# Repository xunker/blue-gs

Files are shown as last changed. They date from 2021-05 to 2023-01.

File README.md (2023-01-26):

# BlueGS: Internal BlueSCSI for Apple IIgs and //e

*BlueGS* is the internal hard drive your Apple IIgs and //e always *craved*.

Using the [BlueSCSI](https://github.com/erichelgeson/BlueSCSI) SCSI drive emulator and your compatible SCSI card, you have a fully internal hard drive with accessible microSD slot while still keeping your DB-25 connector free for other peripherals.

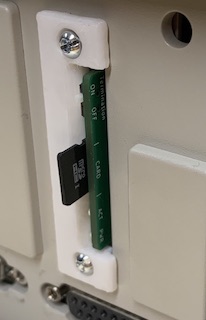
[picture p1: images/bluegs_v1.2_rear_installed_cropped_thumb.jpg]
Close-up of BlueGS installed in IIgs slot

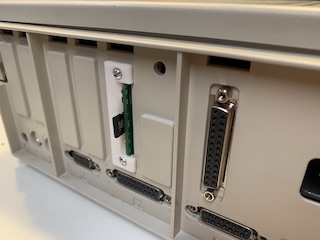
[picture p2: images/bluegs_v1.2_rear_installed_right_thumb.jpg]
BlueGS installed in IIgs slot, right side

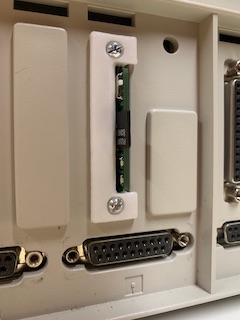
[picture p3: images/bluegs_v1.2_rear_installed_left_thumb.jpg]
BlueGS installed in IIgs slot, left side


# How it works

BlueGS connects between your SCSI card and its external DB-25 connector to give you a seamless installation. The BlueGS module itself mounts in a free DB-25 connector cutout in the rear of your IIgs or //e.

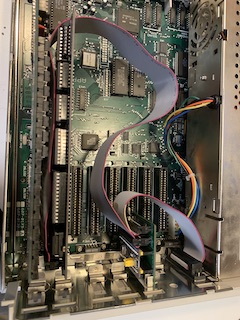
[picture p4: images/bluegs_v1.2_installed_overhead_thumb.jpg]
Overhead view of BlueGS in IIgs slot

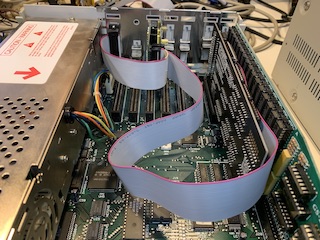
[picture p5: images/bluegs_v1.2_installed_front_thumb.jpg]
Frontal view of BlueGS in IIgs slot


# Features

* Gives your Apple IIgs or //e an internal, cable-free hard drive
* Can be powered from SCSI termination power only (if present)
* "Termination Power" mod is not required (when powered from auxiliary 5V source)
* Can *provide* termination power to the SCSI bus (when powered from a 5V source such as the Game IO connector or card slot)
* Built-in termination that is controlled with a single switch
* Active termination ICs instead of passive termination resistors, reduces power consumption by over 2/3rds
* Reverse current and voltage protection with overcurrent prevention for auxiliary 5V input
* Connection for external drive activity LED

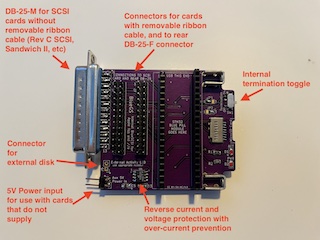
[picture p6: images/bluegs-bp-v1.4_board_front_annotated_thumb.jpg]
Annotated picture of front of BlueGS v1.2

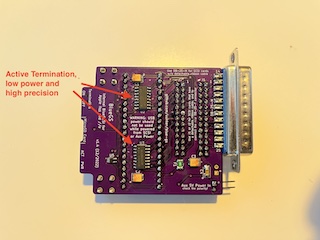
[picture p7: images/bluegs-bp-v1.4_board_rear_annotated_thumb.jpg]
Annotated picture of rear of BlueGS v1.2


# Compatible SCSI cards

Tested:
* [GGLabs A2SCSI](https://gglabs.us/node/2071) - a clone of the Apple Rev C SCSI card
* Apple Rev C SCSI and clones
* Apple High-Speed SCSI ("Sandwich II")
* Ramfast SCSI

Assumed to work:
* GSE-Reactive SCSI Card

Untested:
* AMR SCSI
* Cirtech SCSI/Insyder
* SVA Hard Disk Adapter

The CMS SCSI II is currently confirmed **NOT** to work, though it appears to be a (card) firmware issue and not a "bug" with BlueSCSI.

## What if my SCSI card doesn't provide termination power?

Running BlueGS from "termination power" makes installation much easier, but not all SCSI cards have it. For more details, please check out the notes on [Powering BlueGS](POWERING_BLUE-GS.md).

# Performance

Using [BenchmarkD](https://www.brutaldeluxe.fr/products/apple2gs/benchmarked.html) with Apple IIgs (ROM 1, "Fast" speed), GS-RAM Plus w/ 2MB, GGLabs A2SCSI card. Using Blue-Pill-based BlueGS board.

* Read
  * File: 52 KB/s
  * Block-by-block: 36 KB/s
  * With 64K buffer: 79 KB/s
* Write (File): 37 KB/s

# Can I use it on things besides the IIgs and //e?

Yes! It's a standard BlueSCSI device and uses the standard BlueSCSI V1 firmware. In fact, the built-in DB-25 connector makes it the perfect external SCSI drive as well!

BlueGS can be mounted internally in any computer that has an open cutout for a DB-25 connector.

## ✅ Compatible Apple clones

These computers *do* have rear DB-25 cutouts and so BlueGS should be able to mount properly, but are untested.

* Franklin Ace 2000/2100/2200
* Basis 108

## 🚫 Apple II/II+ and similar clones

BlueGS will function in an Apple II or II+, but you will not be able to mount it because it uses "V" shaped cutouts instead of D-Subminiature connector cutouts like the //e and IIgs have.

Many Apple II clones use the same rear cutout design and have the same mounting limitation. **A mounting solution for these machine is planned**.

* Franklin Ace 100/1000/1200
* Pravetz-8
  - Includes the -8, -82, -8M, -8A, -8E, and -8C
* Unitron (Brazil)
* Ci Base-48 and Pineapple (Korea)

# Assembly

If you purchased BlueGS as a self-assemble kit or are using your own PCBs, please follow the instructions in the "[assembly](assembly/)" directory.

If your BlueGS was purchased fully-assembled, please move on to the "[Installation](installation/)" section.
# Installation

Installation guides can be found in the "[installation](installation/)" directory.
# Schematics

[V1.4 Schematic](schematics/schematic_v1.4.pdf) (**FINAL**, recommended design)

<details>
  <summary>Older Schematics</summary>

[V1.3 Schematic](schematics/schematic_v1.3.pdf)

[V1.2 Schematic](schematics/schematic_v1.2.pdf)

[V1.1 Schematic](schematics/schematic_v1.1.pdf)

</details>

# EDA/Kicad and Gerber Files

Kicad of current design can be found in [kicad](kicad/) directory.

# Credits

This project would not be possible without the work done by [ztto](https://github.com/ztto/ArdSCSino-stm32), [Tambo](https://twitter.com/h_koma2), [Eric Helgeson](https://github.com/erichelgeson/BlueSCSI), [Androda](https://androda.work/), and many others.

The "Blue Pill" footprint was originally created by [Yet-Another-Average-Joe](https://github.com/yet-another-average-joe/Kicad-STM32).

Symbol and footprint for Molex 105162-0001 MicroSD slot created by [SnapEDA user HMantz](https://www.snapeda.com/parts/105162-0001/Molex/view-part/).

# License

See [LICENSE.md](LICENSE.md).

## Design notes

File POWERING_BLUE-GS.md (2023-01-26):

# Powering BlueGS

There are 4 ways to power your BlueGS board, listed here from "most easy" to "least easy".

## Termination Power from SCSI card

If your SCSI card provides [Termination Power](#what-is-termination-power), then you only have to BlueGS to your SCSI card using the included flat 26-pin cable or DB-25-M connector. No additional steps are required, and BlueGS should turn on the moment that the computer is powered up.

## Termination Power from another SCSI device

If your SCSI card does not provide Termination Power, then you can provide the necessary power through another SCSI device connected to the DB-25 connector.

Most external SCSI devices will provide the necessary Termination Power. To power BlueGS this way:
* Connect the new SCSI device to the DB-25 connector
* On BlueGS, switch "Termination" to "off"
* Ensure that the new SCSI device is terminated, either via a switch (if it has one, such as on the IOmega Zip Drive) or an external terminator that connects to one of the SCSI ports of the device.

This external device must be powered-on *before* the IIgs turns on.

## +5V from inside the computer

You can power BlueGS via the "Aux 5V Power In" connector, using a 5V source in your computer. This can be from the Game IO port, a card slot, or a tap from the power supply rail.

If you power BlueGS using this connector, it will also send termination power to any other devices on the SCSI bus that may need it -- such as another BlueSCSI device!

Older versions of BlueGS could be powered by the 12V fan connector in the IIgs, but that has been removed in 1.4 and higher.

## USB port on Blue Pill board

You can power BlueGS using the USB connector on the Blue Pill module as long as you are not also using SCSI Termination Power or 5V aux power.

### Why can't I use USB while BlueGS is powered from SCSI or Aux?

There is a design flaw on the Blue Pill board where power sent to the +5V pin of the board can then be sent *back* through the USB connector. This "backflow" can potentially cause damage to whatever is providing USB power and so it strongly recommended that you do not use USB to power BlueGS while connected to SCSI Termination Power or aux power.

If there is no termination power on your bus and BlueGS is not using the aux power connector, then there is no danger of "backflow" and USB power can be used.

# What is Termination Power?

Very briefly, "Termination Power" is electrical current that is used to power devices called "Terminators". A "Terminator" is a device connected to the end of a "bus" (the cable/wire) to show where the end is.

If you think of the SCSI bus as a water pipe and each drive on the bus as a water tap connected to the pipe, then a Terminator is the cap at the end of the pipe.

# What SCSI cards do/don't provide Termination Power?

While many SCSI cards do not provide termination power, there are some that can be modified to that they will.

## Cards that DO provide Termination Power

* [GGLabs A2SCSI](https://gglabs.us/node/2071)
* RAMFast SCSI - controlled by JP1 or DIP #1, see manual for details

## Cards that DON'T provide Termination Power

* Apple Rev B SCSI
  - Can be modified to provide termination power
* Apple Rev C SCSI
  - Can be modified to provide termination power
* Apple High-Speed SCSI ("Sandwich II")
  - Can be modified to provide termination power

## Unknown cards

* AMR SCSI
* CMS SCSI II
* Cirtech SCSI/InSyder
* GSE-Reactive SCSI Card
* SVA Hard Disk Adapter

# How can I tell if my SCSI card is providing Termination Power?

If your card is not in one of the lists above, then the easiest way is to connect BlueGS and see if it turns on when the the computer is powered on.

If you have a multi-meter, you can check the voltage on pin 25 of the DB-25 connector. If termination power is provided, this pin should read between 4.5 and 5 volts.

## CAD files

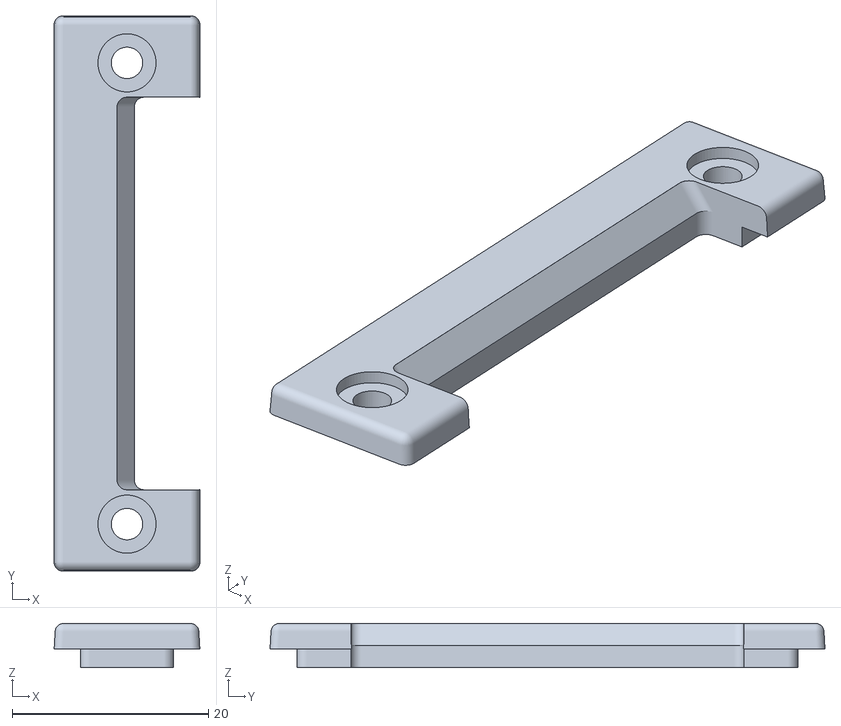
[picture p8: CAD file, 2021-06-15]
slot_cover/blue-gs-cover.stl
14.8 x 56.5 x 4.50

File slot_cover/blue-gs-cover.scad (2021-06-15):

face_length = 56.55;
face_width = 14.85;
face_thickness = 2.6;
face_inset = (face_width - 14.65)/2; // amount the sides will slope inward, per side

rear_length = 51.0;
rear_width = 9.5;
rear_thickness = 4.5 - face_thickness;

screw_spacing = 47;
screw_d = 3.1;
screw_head_d = screw_d * 1.85;
screw_head_t = face_thickness * 0.4;
slope_screw_heads = false;

notch_width = 7.5;
notch_length = 39;
notch_x_offset = 4.5; // from centreline

total_thickness = face_thickness + rear_thickness;

ff = 0.01;

$fn = 64;

// inset is how far in the sides will slop, per side
module rounded_top_rectangle(width, length, height, inset=0, rad=6) {
  hull() {
    // rounded sides
    // translate([rad,rad,0]) cylinder(r=rad, h=height-rad);
    // translate([width-rad,rad,0]) cylinder(r=rad, h=height-rad);
    // translate([width-rad,length-rad,0]) cylinder(r=rad, h=height-rad);
    // translate([rad,length-rad,0]) cylinder(r=rad, h=height-rad);
    translate([rad,rad,0]) cylinder(r=rad, h=ff);
    translate([width-rad,rad,0]) cylinder(r=rad, h=ff);
    translate([width-rad,length-rad,0]) cylinder(r=rad, h=ff);
    translate([rad,length-rad,0]) cylinder(r=rad, h=ff);

    // rounded top
    translate([rad+inset,rad+inset,height-rad]) sphere(r=rad);
    translate([width-(rad+inset),(rad+inset),height-rad]) sphere(r=rad);
    translate([width-(rad+inset),length-(rad+inset),height-rad]) sphere(r=rad);
    translate([(rad+inset),length-(rad+inset),height-rad]) sphere(r=rad);

  }
}

module rounded_rectangle(width, length, height, inset=0, rad=6, fn=32) {
  hull() {
    // rounded sides
    translate([rad,rad,0]) cylinder(r=rad, h=height);
    translate([width-rad,rad,0]) cylinder(r=rad, h=height);
    translate([width-rad,length-rad,0]) cylinder(r=rad, h=height);
    translate([rad,length-rad,0]) cylinder(r=rad, h=height);
  }
}

module face() {
  intersection() {
    cube([face_width, face_length, face_thickness]);

    rounded_top_rectangle(face_width, face_length, face_thickness, inset=face_inset, rad=face_thickness/3);

  }
}

module rear() {
  rounded_rectangle(rear_width, rear_length, rear_thickness, rad=1);
}

module blank_cover() {
  difference() {
    union() {
    translate([(face_width-rear_width)/2, (face_length-rear_length)/2, 0]) rear();
    translate([0, 0, rear_thickness]) face();
    }
    translate([face_width/2, face_length/2, -ff]) for (sign=[1,-1]) {
      translate([0, (screw_spacing/2)*sign, 0]) {
        cylinder(d=screw_d, h=total_thickness+(ff*2));
        translate([0, 0, total_thickness-screw_head_t]) {
          if (slope_screw_heads) {
            cylinder(d1=screw_d, d2=screw_head_d, h=screw_head_t+(ff*2));
          } else {
            cylinder(d=screw_head_d, h=screw_head_t+(ff*2));
          }
        }
      }
    }
  }
}

difference() {
  blank_cover();
  translate([((face_width-notch_width)/2) + notch_x_offset, (face_length-notch_length)/2, -ff]) {
    flared_width = (face_width-notch_width)*1.5;
    flared_length = notch_length * 1.0;

    rounded_rectangle(notch_width, notch_length, total_thickness/2, rad=1);
    translate([0, 0, (total_thickness/2)-ff]) hull() {
      rounded_rectangle(notch_width, notch_length, ff, rad=1);
      translate([(notch_width-flared_width)/2, (notch_length-flared_length)/2, (total_thickness/2)+ff])
        rounded_rectangle(flared_width, flared_length, ff, rad=1);
    }
  }
}

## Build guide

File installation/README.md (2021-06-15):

# BlueGS Installation Guide

<!-- TOC -->

- [BlueGS Installation Guide](#bluegs-installation-guide)
- [Introduction](#introduction)
- [Steps](#steps)
- [Open computer case](#open-computer-case)
- [Remove rear slot cover](#remove-rear-slot-cover)
- [Unscrew DB-25 Connector](#unscrew-db-25-connector)
- [Remove SCSI card](#remove-scsi-card)
- [Move DB-25 connector](#move-db-25-connector)
- [Attach ribbon cable](#attach-ribbon-cable)
- [Install BlueGS in rear slot](#install-bluegs-in-rear-slot)
- [Reinstall DB-25 connector in rear slot](#reinstall-db-25-connector-in-rear-slot)
- [Reinstall SCSI card and close computer case](#reinstall-scsi-card-and-close-computer-case)
- [Insert MicroSD card, check termination](#insert-microsd-card-check-termination)
- [Power on and enjoy!](#power-on-and-enjoy)

<!-- /TOC -->
# Introduction

Before continuing, please ensure you have all the required parts ready:

* Assembled BlueGS board, including "Blue Pill" module (See [assembly guide](../assembly/) for more info)
* Rear slot cover
* 2x screws for rear slot cover ("US Machine Screw" size: #4-40, length: > 0.75in/15mm)
* 26-pin ribbon cable

# Open computer case

Turn off the computer power switch and unplug the power connector.

Open the top cover of the computer case.

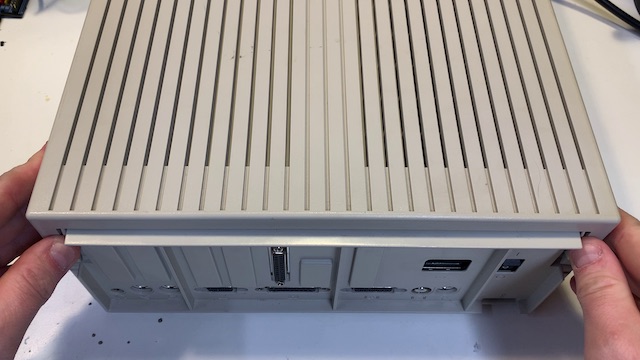
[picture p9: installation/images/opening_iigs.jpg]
Opening IIgs cover


Before continuing, it is recommended that your remove any static electricity from you body by "grounding" yourself. To do this, touch the metal part of any electrical appliance that uses a grounded/earthed electrical plug (the outside of a metal surge protector, for example).

# Remove rear slot cover

Find an unused DB-25 slot cover. The DB-25 slots are the longest, and a usable slot will be the same length as the slot already used for the external connector of your SCSI card.

To remove the cover, grasp the metal tab on the inside of the slot and turn counter-clockwise for 1/4 of a turn. Remove the metal tab, and the plastic slot cover should fall away.

Keep both the metal tab and the plastic cover for later re-use as these parts are very hard to replace.

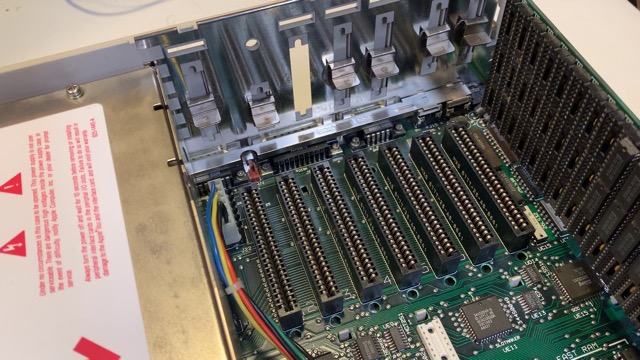
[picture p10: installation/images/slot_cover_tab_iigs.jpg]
IIgs slot cover tabs

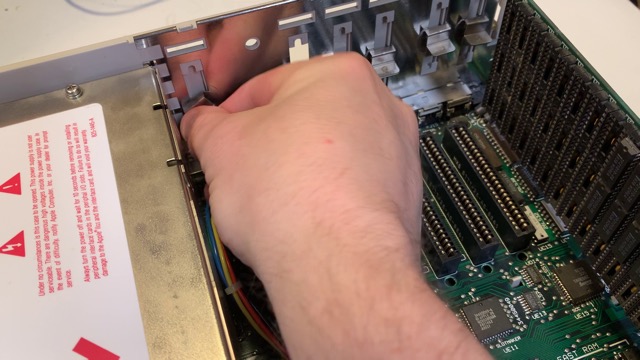
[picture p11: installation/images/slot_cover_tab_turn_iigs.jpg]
IIgs slot cover tab removal


# Unscrew DB-25 Connector

Find the existing connector for the SCSI card on the rear of the computer. It may look similar to connector for a serial card, so make sure you find the correct connector. Using a small socket or needle-nose pliers, loosen the two screw mounts on either end of the connector and remove them. The DB-25 connector should now be freed.

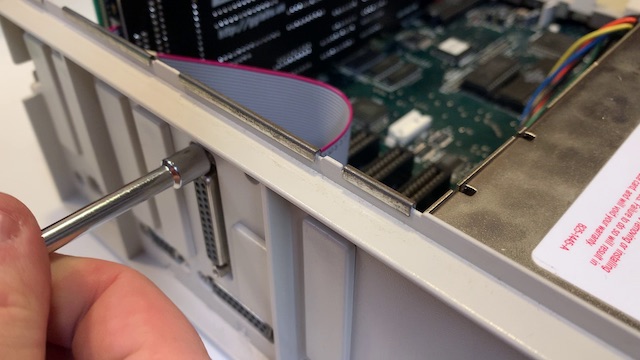
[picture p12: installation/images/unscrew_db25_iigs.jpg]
IIgs DB-25 Connector Removal


# Remove SCSI card

Find your SCSI card (typically in slot #7) and remove it by pulling it firmly upward.

IMPORTANT: While removing the card, ensure the cable for the DB-25 connector (see previous step) is kept away from the metal tabs on the rear of the computer case. These tabs can be **sharp** and can damage the cable.

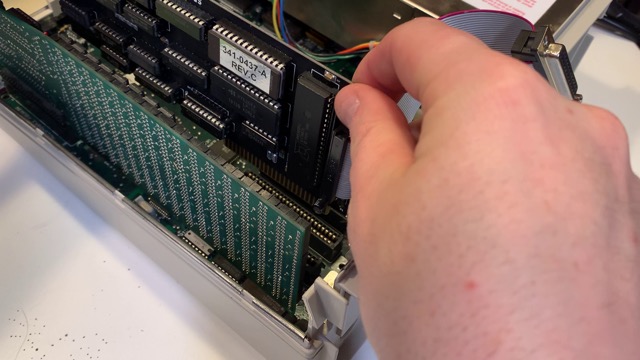
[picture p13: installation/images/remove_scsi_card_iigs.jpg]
IIgs SCSI Card Removal

# Move DB-25 connector

With the SCSI card out of the machine, look at the long rectangular connection where the DB-25 cable connects to the SCSI card (known as an "IDC connector"). Note where "Pin 1" is oriented. Pin 1 is usually marked by a red stripe.

Next, remove the DB-25 connector from the SCSI card. Do this by grasping the IDC connector on the SCSI card and gently pulling away from the board.

Next, take the IDC connector on the DB-25 cable and connect it the BlueGS board. It can connect to *either* connector J1 or J2.

When connecting the cable, make sure that **Pin 1** is correctly aligned. On the cable, Pin 1 is usually marked by a red stripe. On BlueGS, Pin 1 for connectors J1 and J2 are those closest to the top-left corner and the pins are marked with a "1" on the board next to them.

IMPORTANT: Again, *make sure* pin 1 is correctly aligned.

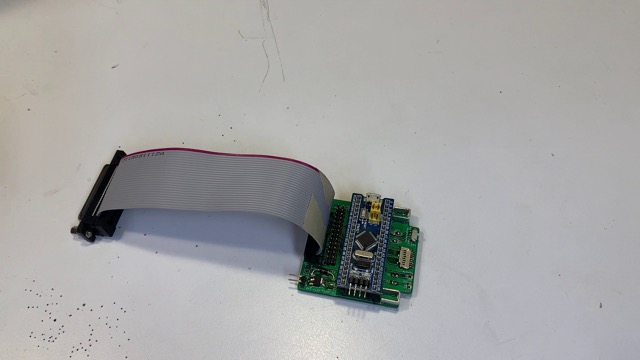
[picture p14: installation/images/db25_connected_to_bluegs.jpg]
DB-25 connected to BlueGS


# Attach ribbon cable

Take the included ribbon cable and attach one end to BlueGS. Use either J1 or J2, whichever connector is not used by the DB-25 connector in the previous step. As before, ensure that Pin 1 is correctly aligned.

Then, connect the other end of the ribbon cable to the SCSI card. Plug it in so that Pin 1 of the ribbon cable is in the same place where Pin 1 of the DB-25 cable was previously.

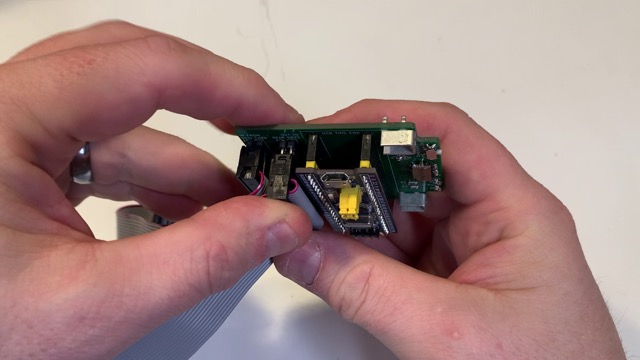
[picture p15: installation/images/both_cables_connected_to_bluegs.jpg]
DB-25 and ribbon cable connected to BlueGS


# Install BlueGS in rear slot

Place BlueGS so the edge with the MicroSD slot, LEDs, and switch is inside one of the open slots on the rear of the computer. It is recommended to orient BlueGS so that the USB port is pointed upwards.

Place the included slot cover on the *outside* of the case over the appropriate slot and thread the included screws through the two screw holes and in to the brackets on BlueGS.

Once the screws are correctly threaded, gently tighten them down with a screwdriver until BlueGS is firmly attached to the slot.

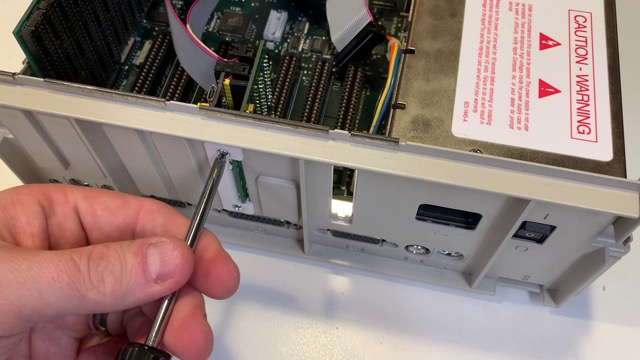
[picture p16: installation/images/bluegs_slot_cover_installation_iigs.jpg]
BlueGS in IIgs rear slot


# Reinstall DB-25 connector in rear slot

In the remaining open slot, reinstall the DB-25 connector.

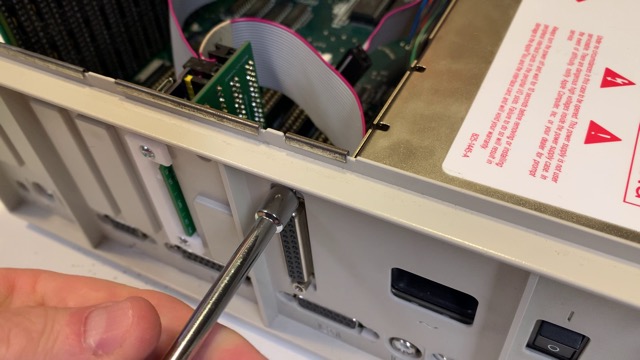
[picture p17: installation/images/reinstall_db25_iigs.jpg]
Reinstall DB-25 connector in IIgs rear slot


# Reinstall SCSI card and close computer case

Reinstall the SCSI card in the correct slot and replace the cover on the computer.

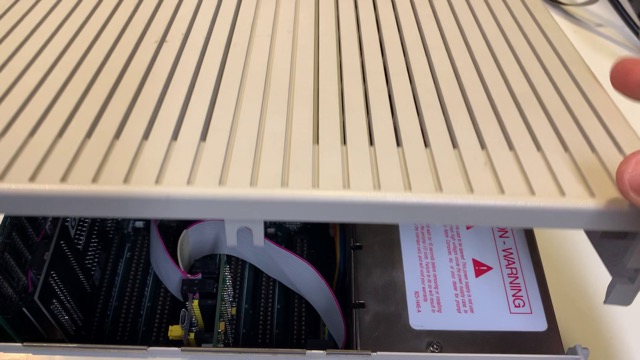
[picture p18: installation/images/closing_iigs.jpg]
Closing IIgs case


# Insert MicroSD card, check termination

Take a MicroSD card that has been previously prepared (instruction [here](https://github.com/erichelgeson/BlueSCSI/wiki/Usage)) and insert it in to the slot on the rear.

If you have no other SCSI devices connected to your computer, the "Termination" switch should be set to "On".

# Power on and enjoy!

Reconnect all necessary cables, turn on the power and enjoy.

The "Power" LED should light the moment the computer turns on, and the "ACT" LED should light whenever the emulated SCSI drive is being read or written.

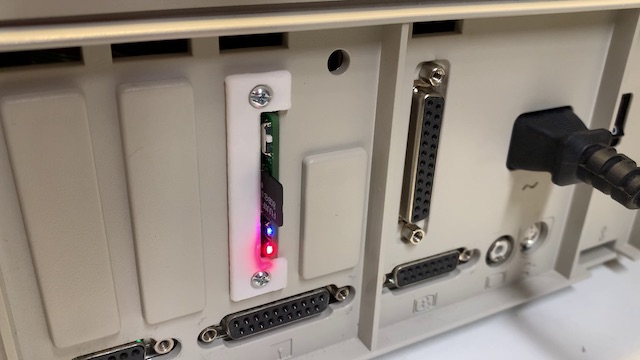
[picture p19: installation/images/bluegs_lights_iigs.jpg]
Show Power and Activity LEDs on BlueGS installed in IIgs


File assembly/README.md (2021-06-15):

# BlueGS Assembly Guide

<!-- TOC -->

- [BlueGS Assembly Guide](#bluegs-assembly-guide)
- [V1.3 Assembly Guide](#v13-assembly-guide)

<!-- /TOC -->
# V1.3 Assembly Guide

The assembly guide for V1.3 of BlueGS is forthcoming, pending test results of the V1.2 design.

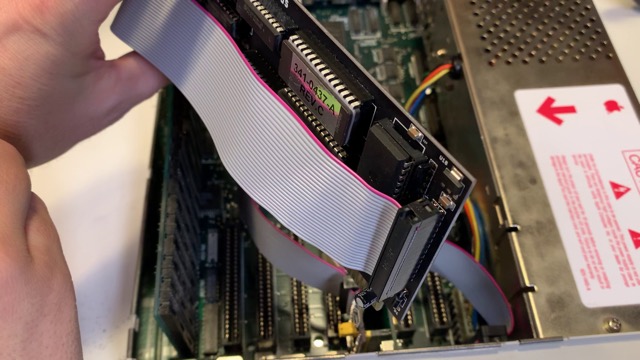
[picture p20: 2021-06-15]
installation/images/cable_on_scsi_card_iigs.jpg

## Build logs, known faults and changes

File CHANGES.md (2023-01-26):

# 1.4

## Replace 12v aux power with 5v

This change is for two reasons:

1) The 7805 regulator is wasteful, especially when the IIgs only has 2.5a on the 12v rail
2) Some models of Apple IIe don't have a fan connector, and most II/II+'s don't

The fix for this will be to get 5v directly from the Game IO (Paddle) Port, a direct tap on the 5V power supply wire, or from a card slot.

This 5v will be used directly via an IC that performs reverse current and over-current protection.

## Branding Changes

The current design has been retroactively branded "BlueGS / BP" to distinguish it from the upcoming RP2040-based "BlueGS / RP"

# 1.3.2

Move External LED connector closer to edge to clear cable plugged in to J1.

Change footprint of D3/D4 to "Diode_SMD:D_SOD-123".

Increase width of 12V and 5V traces.

Move SD Card 3.3v trace to bottom.

Slightly move screw terminal offset to avoid clipped silkscreen warning.

# Older changes not recorded

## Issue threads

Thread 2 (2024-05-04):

Diode in series with F1?

gribbled, 2024-05-04:
Would a series diode here be helpful to avoid external devices back powering the 5V?  Also you mention kits.  Is anyone making one?  Thanks for the great idea.

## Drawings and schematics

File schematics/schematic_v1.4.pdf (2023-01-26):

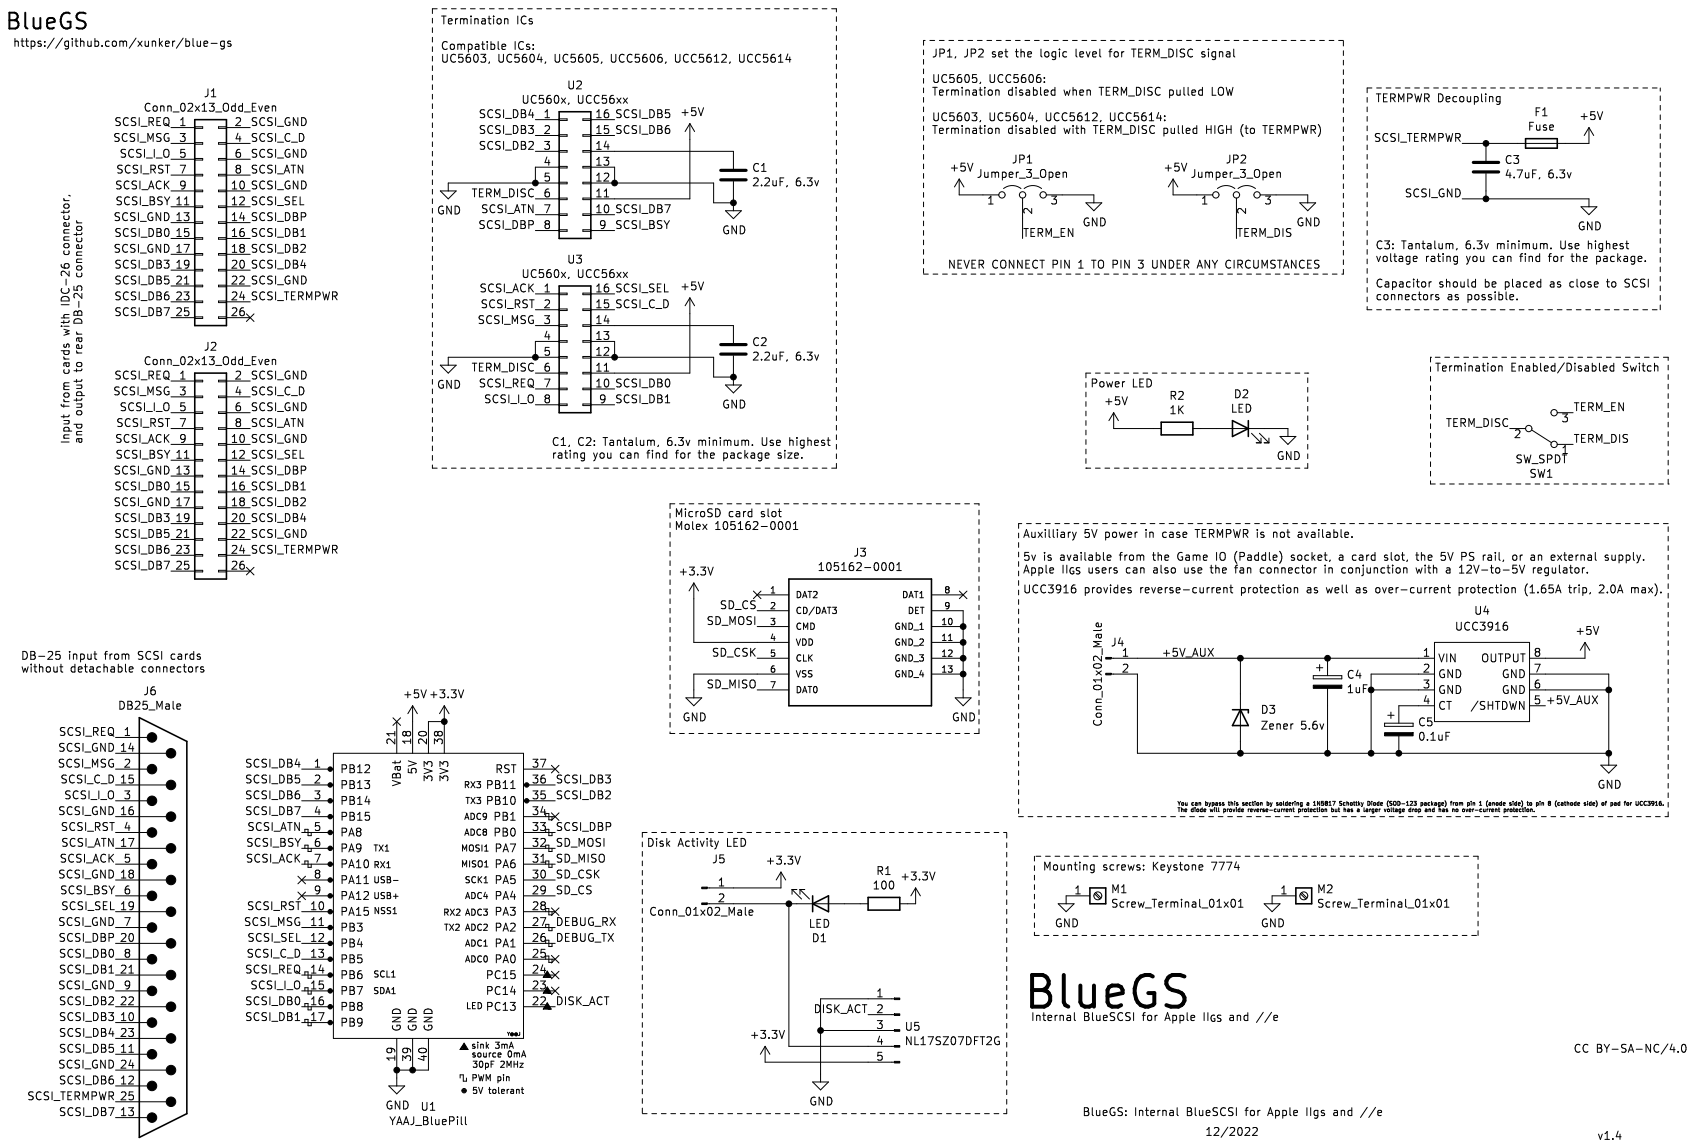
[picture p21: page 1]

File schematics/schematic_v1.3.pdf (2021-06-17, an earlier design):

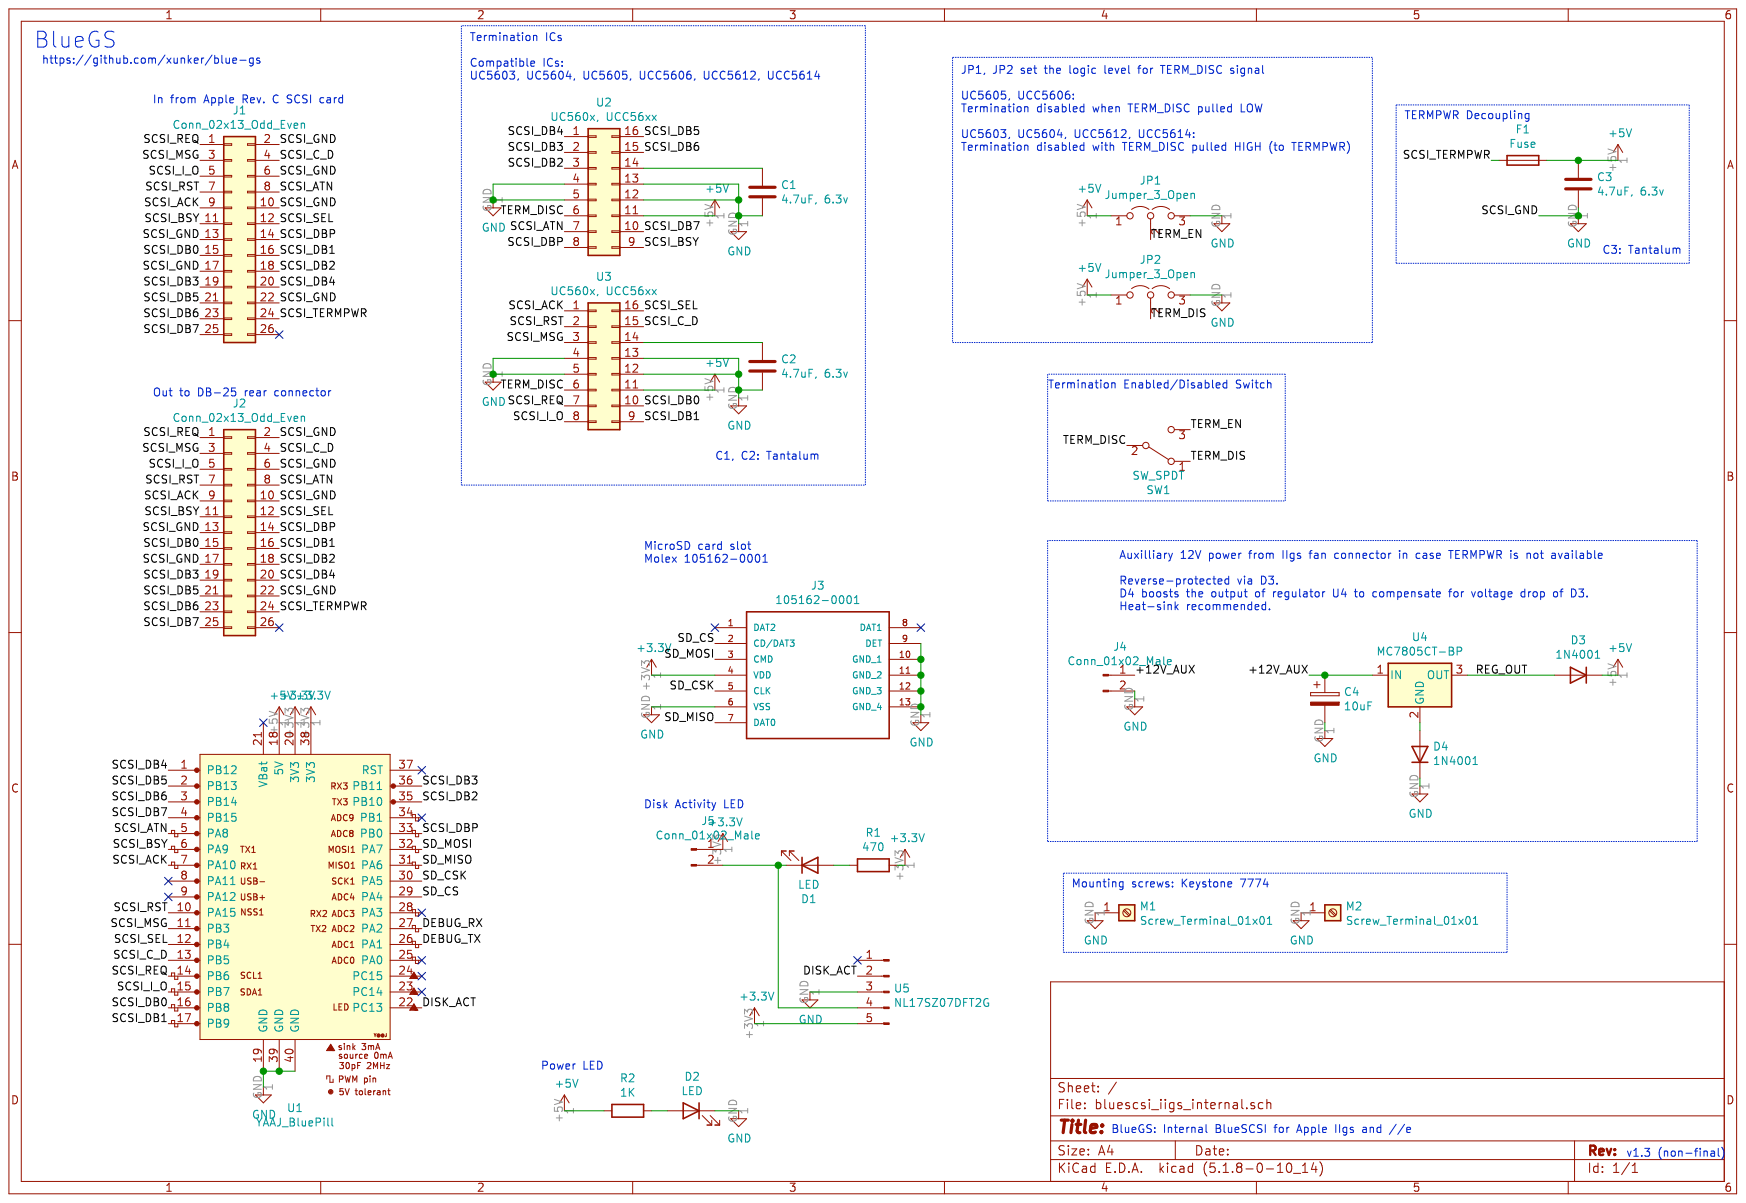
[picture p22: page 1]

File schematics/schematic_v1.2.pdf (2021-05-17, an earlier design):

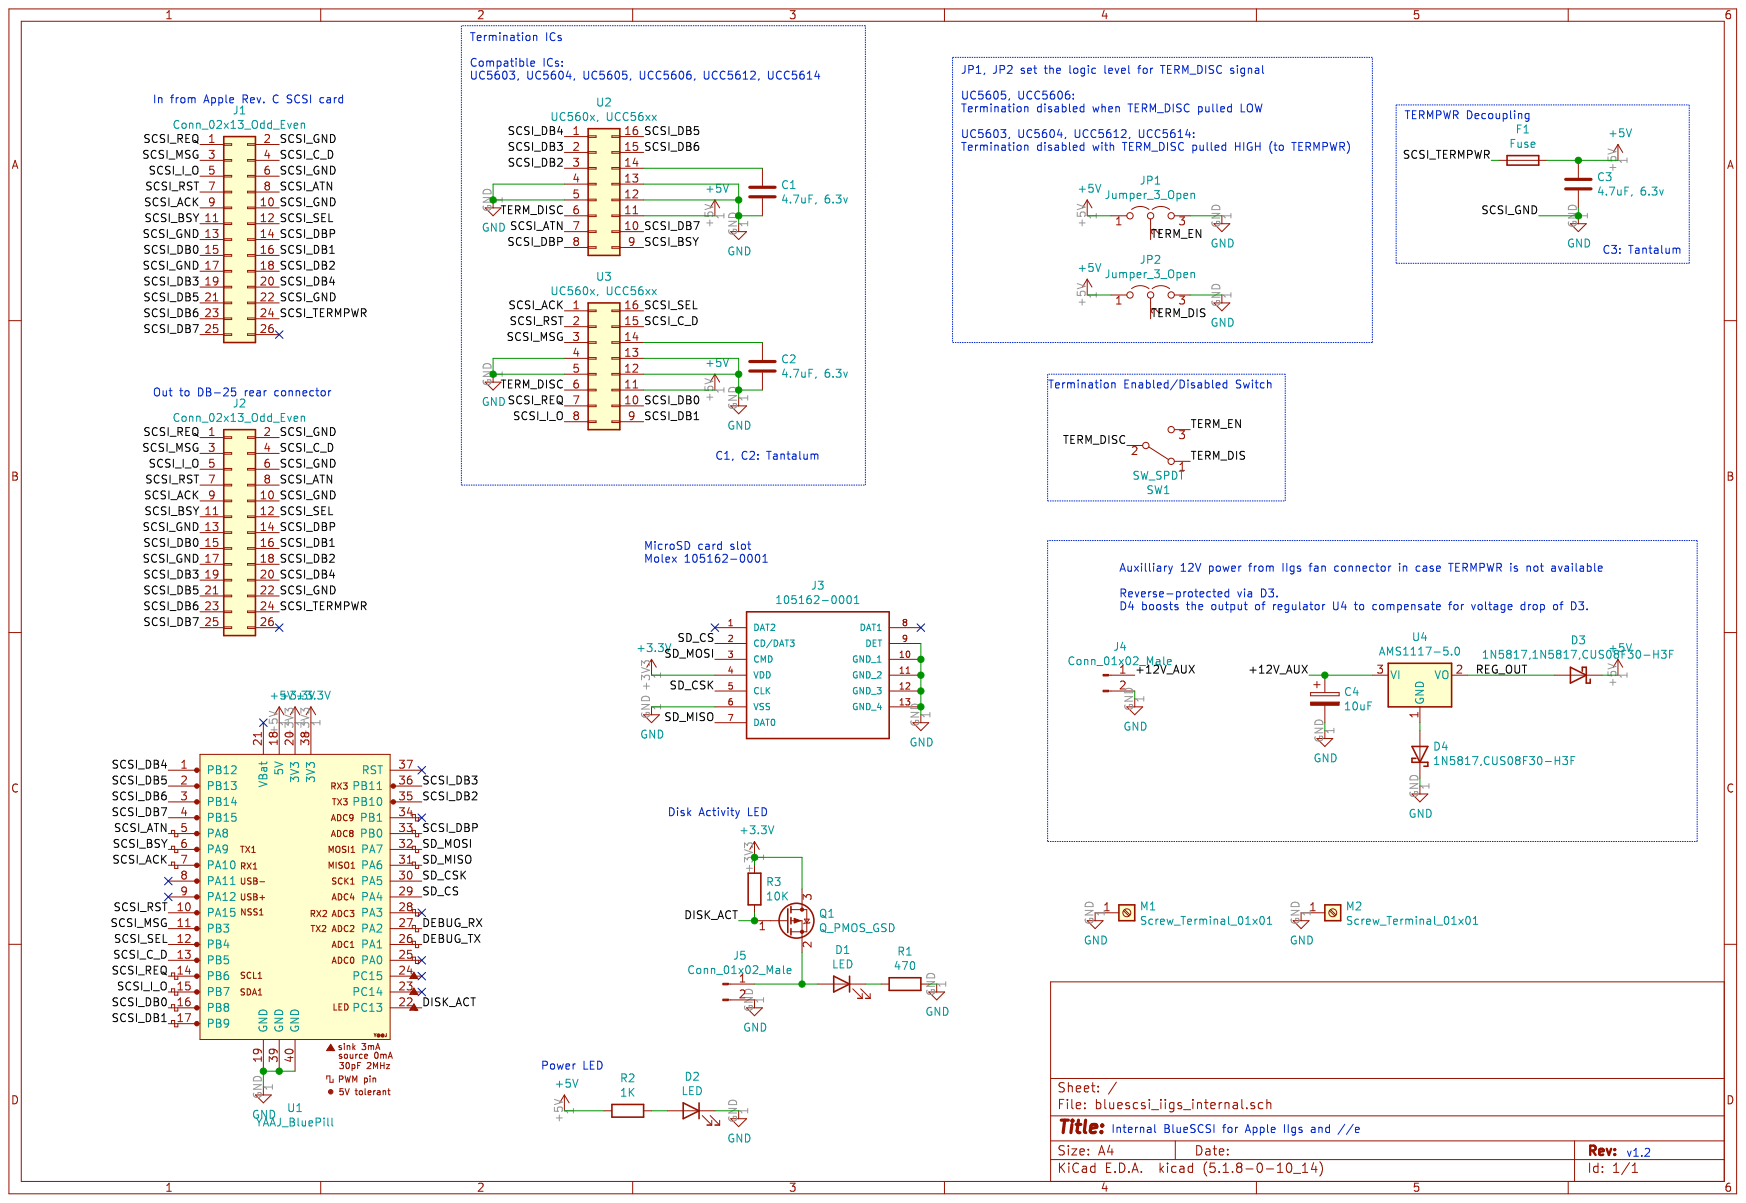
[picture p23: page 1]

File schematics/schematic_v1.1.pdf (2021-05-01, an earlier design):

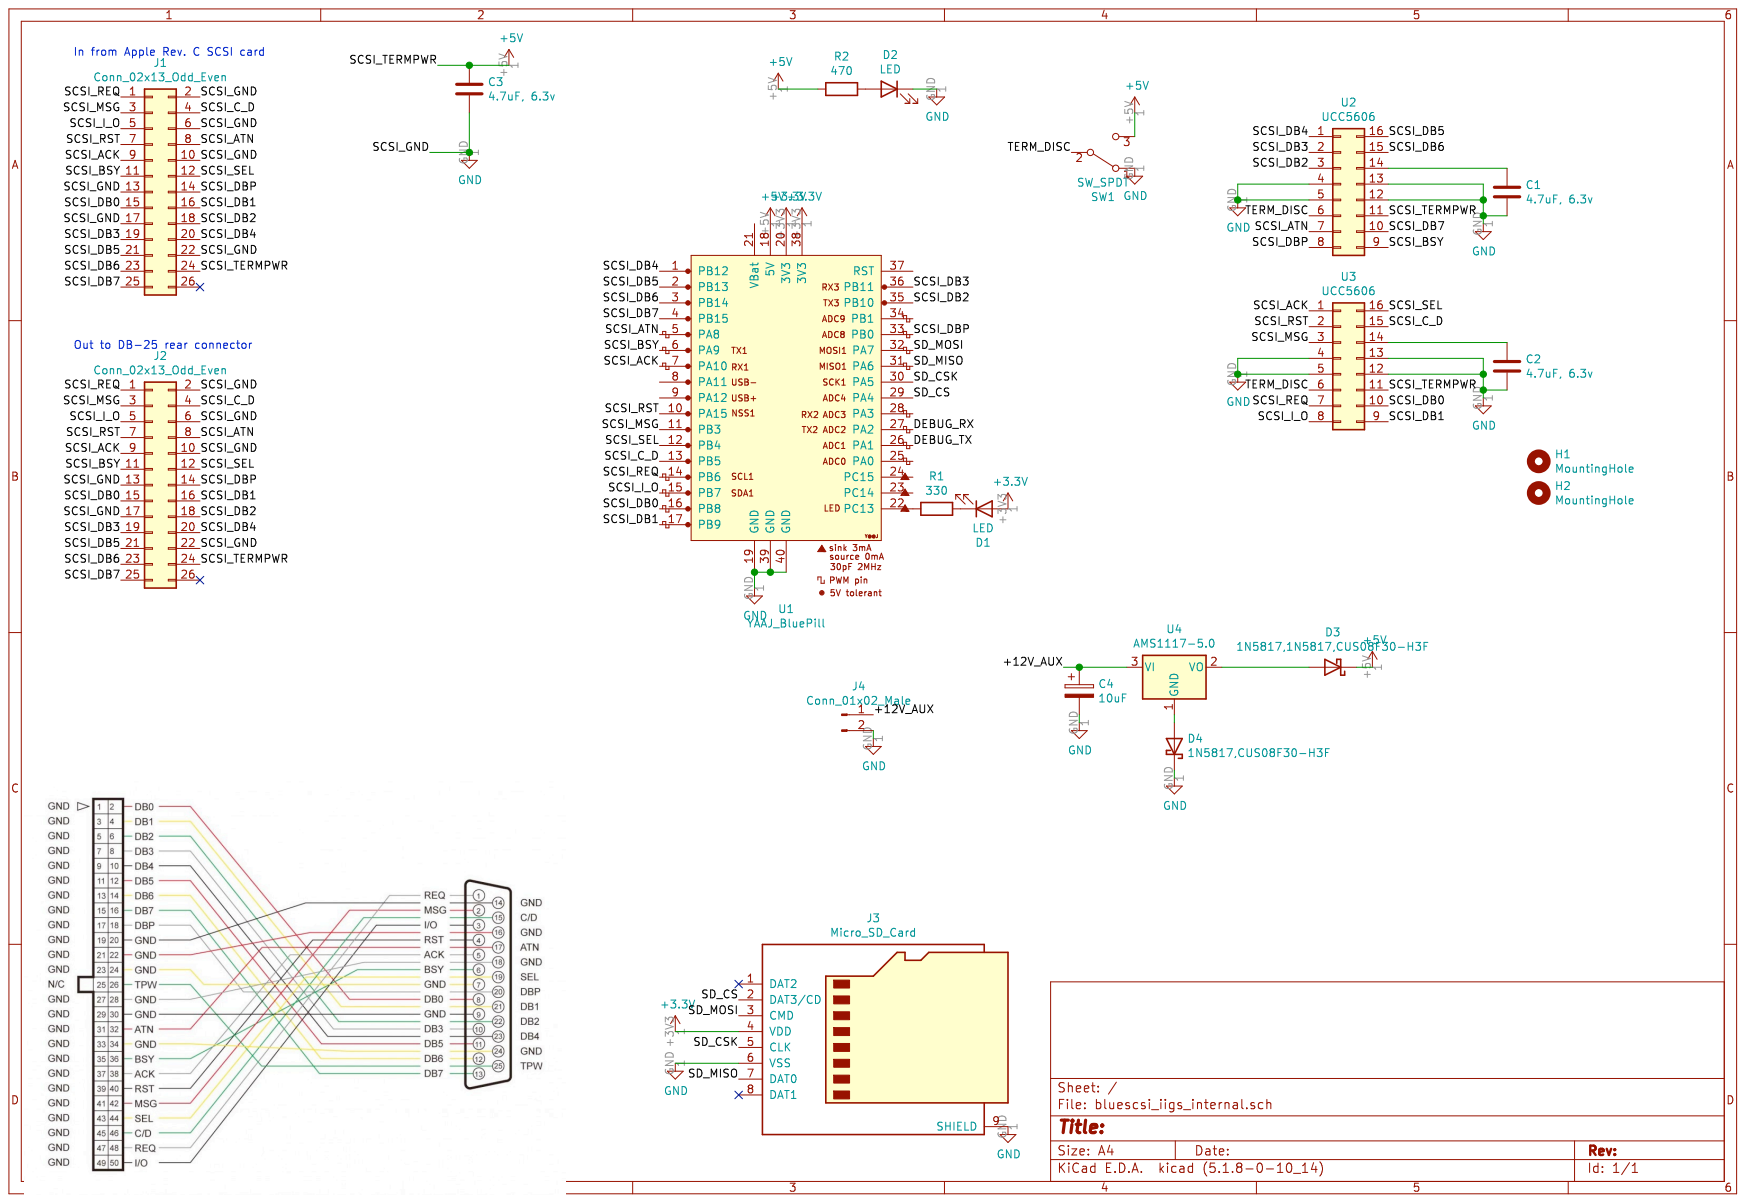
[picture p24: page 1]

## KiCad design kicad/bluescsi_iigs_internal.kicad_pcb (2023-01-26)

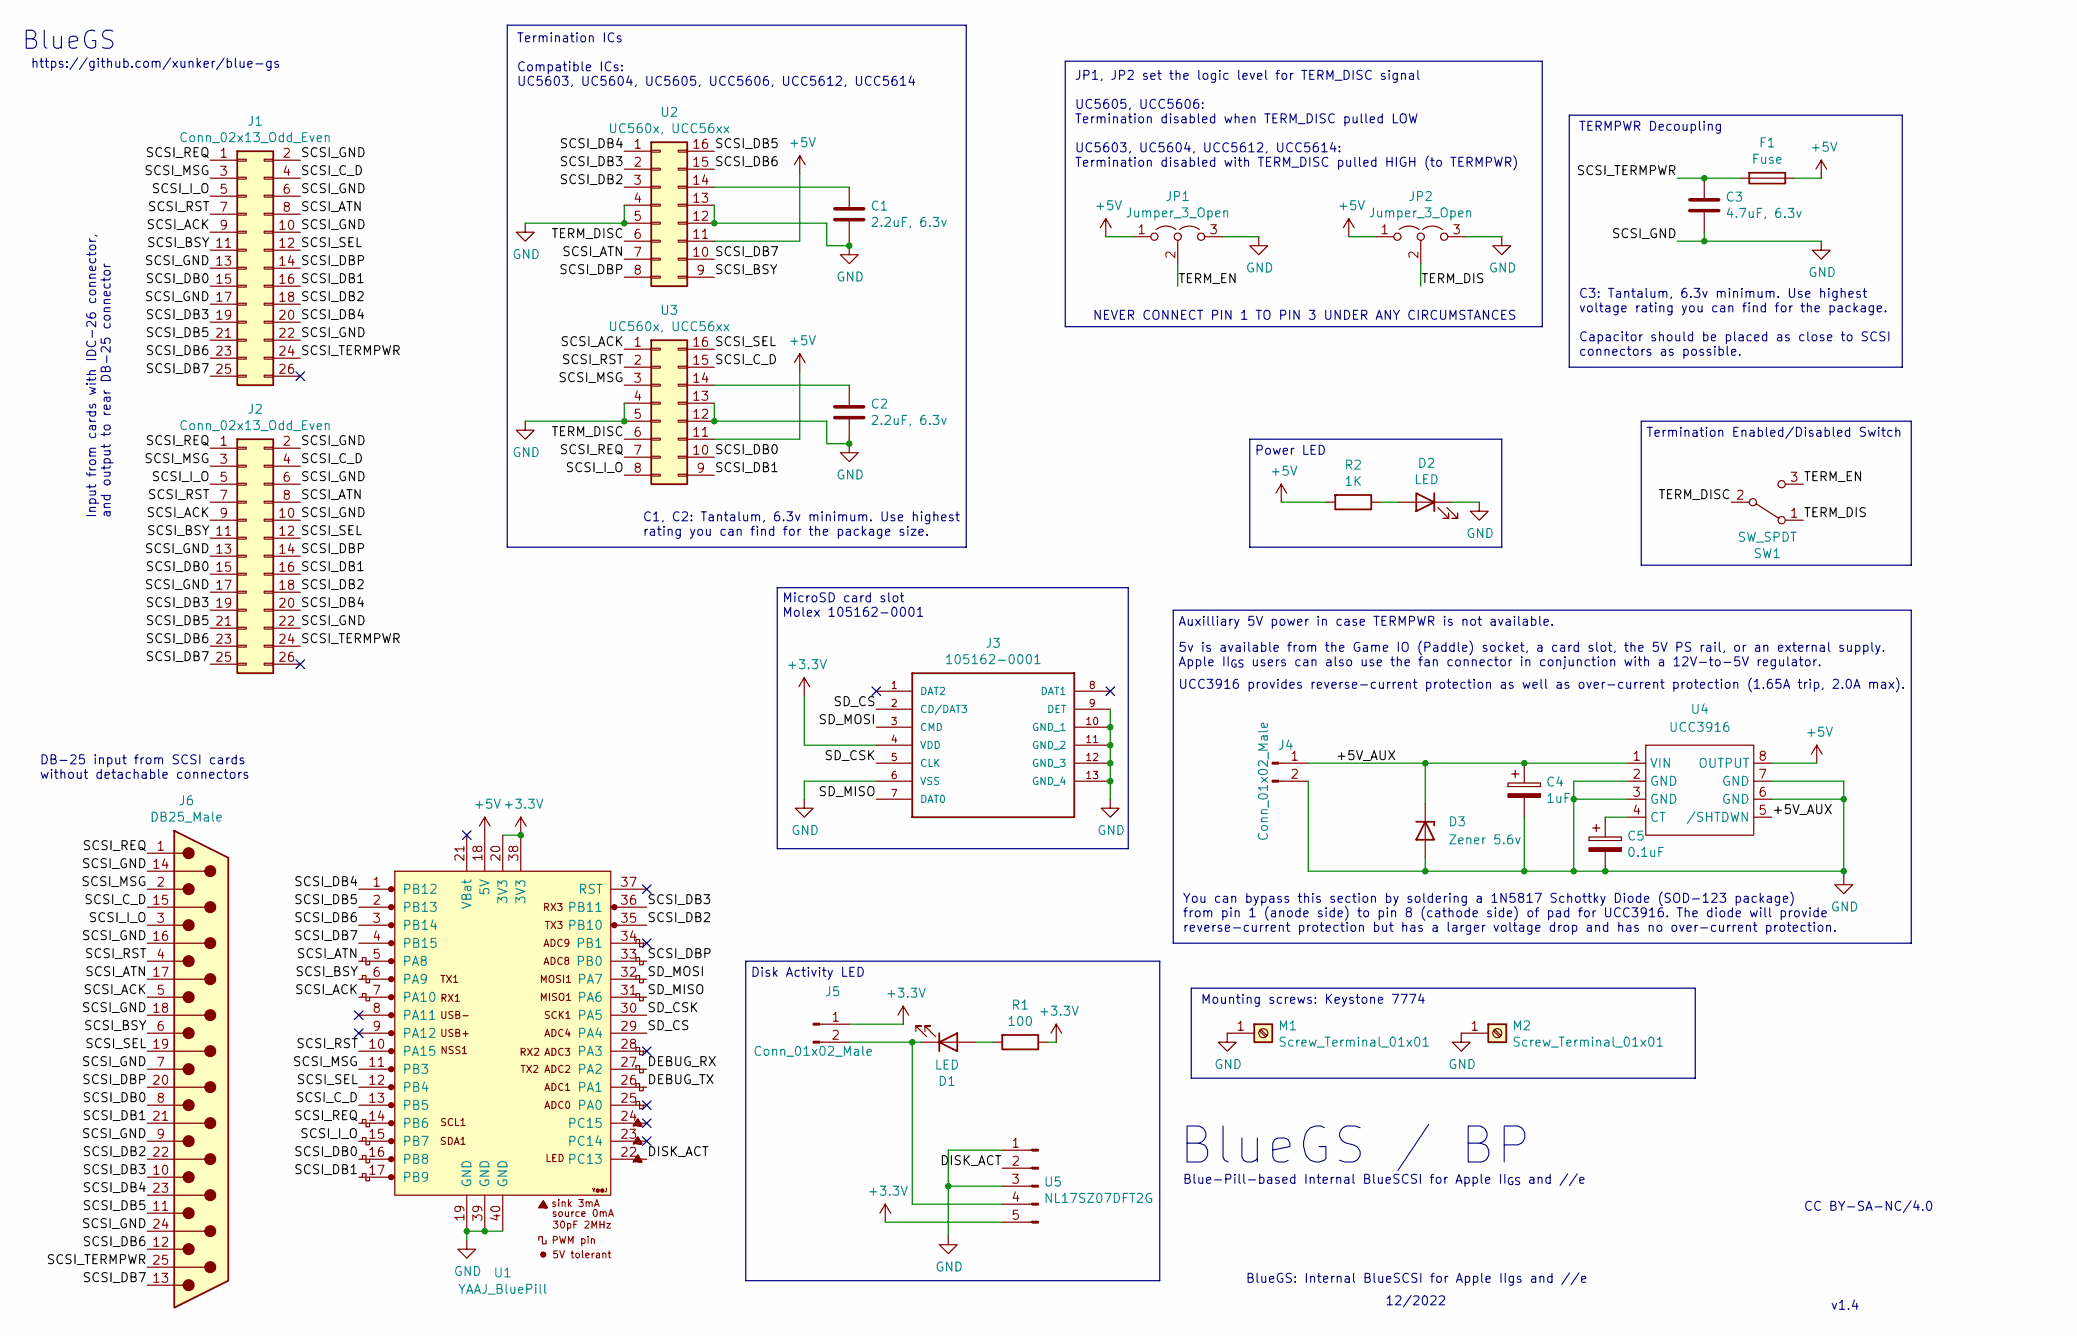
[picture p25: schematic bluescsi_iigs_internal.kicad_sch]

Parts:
C1, C2: 2.2uF, 6.3v; CP_EIA-3528-21_Kemet-B_Pad1.50x2.35mm_HandSolder; MANUFACTURER_PART_NUMBER TAJB225M020RNJ; LCSC part number C444753
C3: 4.7uF, 6.3v; CP_EIA-3528-21_Kemet-B_Pad1.50x2.35mm_HandSolder; MANUFACTURER_PART_NUMBER T494B475K016AT; LCSC part number C918865
C4: 1uF; CP_EIA-3528-21_Kemet-B_Pad1.50x2.35mm_HandSolder; MANUFACTURER_PART_NUMBER T491B105K025AT; LCSC part number C452761
C5: 0.1uF; CP_EIA-3216-10_Kemet-I; MANUFACTURER_PART_NUMBER T491A104K035AT; LCSC part number C122257
D1: LED; LED_0805_2012Metric_Pad1.15x1.40mm_HandSolder; MANUFACTURER_PART_NUMBER HL-PSC-2012H203BC; LCSC part number C497961
D2: LED; LED_0805_2012Metric_Pad1.15x1.40mm_HandSolder; MANUFACTURER_PART_NUMBER NCD0805R1; LCSC part number C84256
D3: Zener 5.6v; D_SOD-123; MANUFACTURER_PART_NUMBER MMSZ5232A_R1_00001; LCSC part number C268592
F1: Fuse; Fuse_1210_3225Metric; MANUFACTURER_PART_NUMBER CFS12V6TR80; LCSC part number C163134
J1, J2: Conn_02x13_Odd_Even; PinHeader_2x13_P2.54mm_Vertical
J3: 105162-0001; MOUSER_PART_NUMBER 538-105162-0001
J4, J5: Conn_01x02_Male; PinHeader_1x02_P2.54mm_Vertical
J6: DB25_Male; DSUB-25_Male_EdgeMount_P2.77mm
JP1, JP2: Jumper_3_Open; SolderJumper-3_P1.3mm_Open_Pad1.0x1.5mm_NumberLabels
M1, M2: Screw_Terminal_01x01; keystone-7774
R1: 100; R_0805_2012Metric_Pad1.20x1.40mm_HandSolder; MANUFACTURER_PART_NUMBER 0805W8F1000T5E; LCSC part number C17408
R2: 1K; R_0805_2012Metric_Pad1.20x1.40mm_HandSolder; MANUFACTURER_PART_NUMBER 0805W8F1001T5E; LCSC part number C17513
SW1: SW_SPDT; SW_SPDT_PCM12; MANUFACTURER_PART_NUMBER PCM12SMTR; LCSC part number C221841
U1: YAAJ_BluePill; YAAJ_BluePill_2
U2, U3: UC560x, UCC56xx; SOIC127P600X175-16N
U4: UCC3916; SOIC-8_3.9x4.9mm_P1.27mm
U5: NL17SZ07DFT2G; SOT-353_SC-70-5_Handsoldering; MANUFACTURER_PART_NUMBER NL17SZ07DFT2G; LCSC part number C113255

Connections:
+3V3: J3.4 (VDD), J5.1, R1.1, U1.20 (3V3), U1.38 (3V3), U5.5
+5V: F1.1, JP1.1 (A), JP2.1 (A), R2.2, U1.18 (5V), U2.11, U3.11, U4.8 (OUTPUT)
/+5V_AUX: C4.1, D3.1 (K), J4.1, U4.1 (VIN), U4.5 (/SHTDWN)
/DEBUG_RX: U1.27 (PA2)
/DEBUG_TX: U1.26 (PA1)
/DISK_ACT: U1.22 (PC13), U5.2
/SCSI_ACK: J1.9, J2.9, J6.5, U1.7 (PA10), U3.1
/SCSI_ATN: J1.8, J2.8, J6.17, U1.5 (PA8), U2.7
/SCSI_BSY: J1.11, J2.11, J6.6, U1.6 (PA9), U2.9
/SCSI_C_D: J1.4, J2.4, J6.15, U1.13 (PB5), U3.15
/SCSI_DB0: J1.15, J2.15, J6.8, U1.16 (PB8), U3.10
/SCSI_DB1: J1.16, J2.16, J6.21, U1.17 (PB9), U3.9
/SCSI_DB2: J1.18, J2.18, J6.22, U1.35 (PB10), U2.3
/SCSI_DB3: J1.19, J2.19, J6.10, U1.36 (PB11), U2.2
/SCSI_DB4: J1.20, J2.20, J6.23, U1.1 (PB12), U2.1
/SCSI_DB5: J1.21, J2.21, J6.11, U1.2 (PB13), U2.16
/SCSI_DB6: J1.23, J2.23, J6.12, U1.3 (PB14), U2.15
/SCSI_DB7: J1.25, J2.25, J6.13, U1.4 (PB15), U2.10
/SCSI_DBP: J1.14, J2.14, J6.20, U1.33 (PB0), U2.8
/SCSI_I_O: J1.5, J2.5, J6.3, U1.15 (PB7), U3.8
/SCSI_MSG: J1.3, J2.3, J6.2, U1.11 (PB3), U3.3
/SCSI_REQ: J1.1, J2.1, J6.1, U1.14 (PB6), U3.7
/SCSI_RST: J1.7, J2.7, J6.4, U1.10 (PA15), U3.2
/SCSI_SEL: J1.12, J2.12, J6.19, U1.12 (PB4), U3.16
/SCSI_TERMPWR: C3.1, F1.2, J1.24, J2.24, J6.25
/SD_CS: J3.2 (CD/DAT3), U1.29 (PA4)
/SD_CSK: J3.5 (CLK), U1.30 (PA5)
/SD_MISO: J3.7 (DAT0), U1.31 (PA6)
/SD_MOSI: J3.3 (CMD), U1.32 (PA7)
/TERM_DIS: JP2.2 (C), SW1.1 (A)
/TERM_DISC: SW1.2 (B), U2.6, U3.6
/TERM_EN: JP1.2 (C), SW1.3 (C)
GND: C1.2, C2.2, C3.2, C4.2, C5.2, D2.1 (K), D3.2 (A), J1.2, J1.6, J1.10, J1.13, J1.17, J1.22, J2.2, J2.6, J2.10, J2.13, J2.17, J2.22, J3.6 (VSS), J3.9 (DET), J3.10 (GND_1), J3.11 (GND_2), J3.12 (GND_3), J3.13 (GND_4), J4.2, J6.7, J6.9, J6.14, J6.16, J6.18, J6.24, JP1.3 (B), JP2.3 (B), M1.1, M2.1, U1.19 (GND), U1.39 (GND), U1.40 (GND), U2.4, U2.5, U2.12, U2.13, U3.4, U3.5, U3.12, U3.13, U4.2 (GND), U4.3 (GND), U4.6 (GND), U4.7 (GND), U5.1, U5.3
unnamed: C1.1, U2.14
unnamed: C2.1, U3.14
unnamed: C5.1, U4.4 (CT)
unnamed: D1.1 (K), J5.2, U5.4
unnamed: D1.2 (A), R1.2
unnamed: D2.2 (A), R2.1

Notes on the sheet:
C3: Tantalum, 6.3v minimum. Use highest voltage rating you can find for the package. Capacitor should be placed as close to SCSI connectors as possible.
BlueGS
NEVER CONNECT PIN 1 TO PIN 3 UNDER ANY CIRCUMSTANCES
Termination Enabled/Disabled Switch
5v is available from the Game IO (Paddle) socket, a card slot, the 5V PS rail, or an external supply. Apple II_{GS} users can also use the fan connector in conjunction with a 12V-to-5V regulator.
BlueGS / BP
12/2022
Power LED
https://github.com/xunker/blue-gs
CC BY-SA-NC/4.0
JP1, JP2 set the logic level for TERM_DISC signal UC5605, UCC5606: Termination disabled when TERM_DISC pulled LOW UC5603, UC5604, UCC5612, UCC5614: Termination disabled with TERM_DISC pulled HIGH (to TERMPWR)
DB-25 input from SCSI cards without detachable connectors
UCC3916 provides reverse-current protection as well as over-current protection (1.65A trip, 2.0A max).
C1, C2: Tantalum, 6.3v minimum. Use highest rating you can find for the package size.
You can bypass this section by soldering a 1N5817 Schottky Diode (SOD-123 package) from pin 1 (anode side) to pin 8 (cathode side) of pad for UCC3916. The diode will provide reverse-current protection but has a larger voltage drop and has no over-current protection.
Mounting screws: Keystone 7774
Auxilliary 5V power in case TERMPWR is not available.
Blue-Pill-based Internal BlueSCSI for Apple II_{GS} and //e
BlueGS: Internal BlueSCSI for Apple IIgs and //e
Disk Activity LED
Input from cards with IDC-26 connector, and output to rear DB-25 connector
MicroSD card slot Molex 105162-0001
TERMPWR Decoupling
Termination ICs Compatible ICs: UC5603, UC5604, UC5605, UCC5606, UCC5612, UCC5614
v1.4

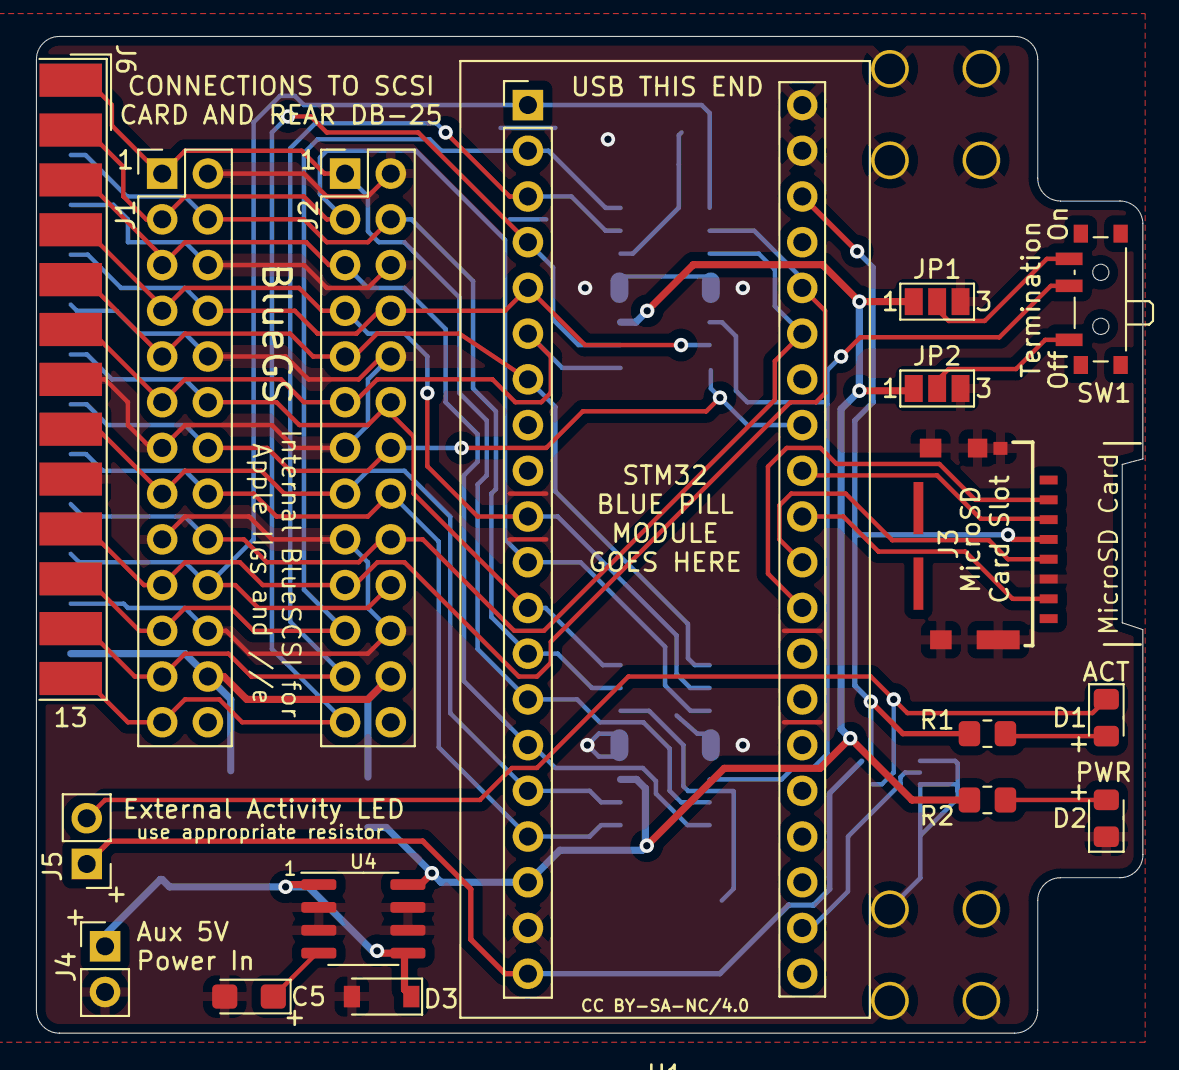
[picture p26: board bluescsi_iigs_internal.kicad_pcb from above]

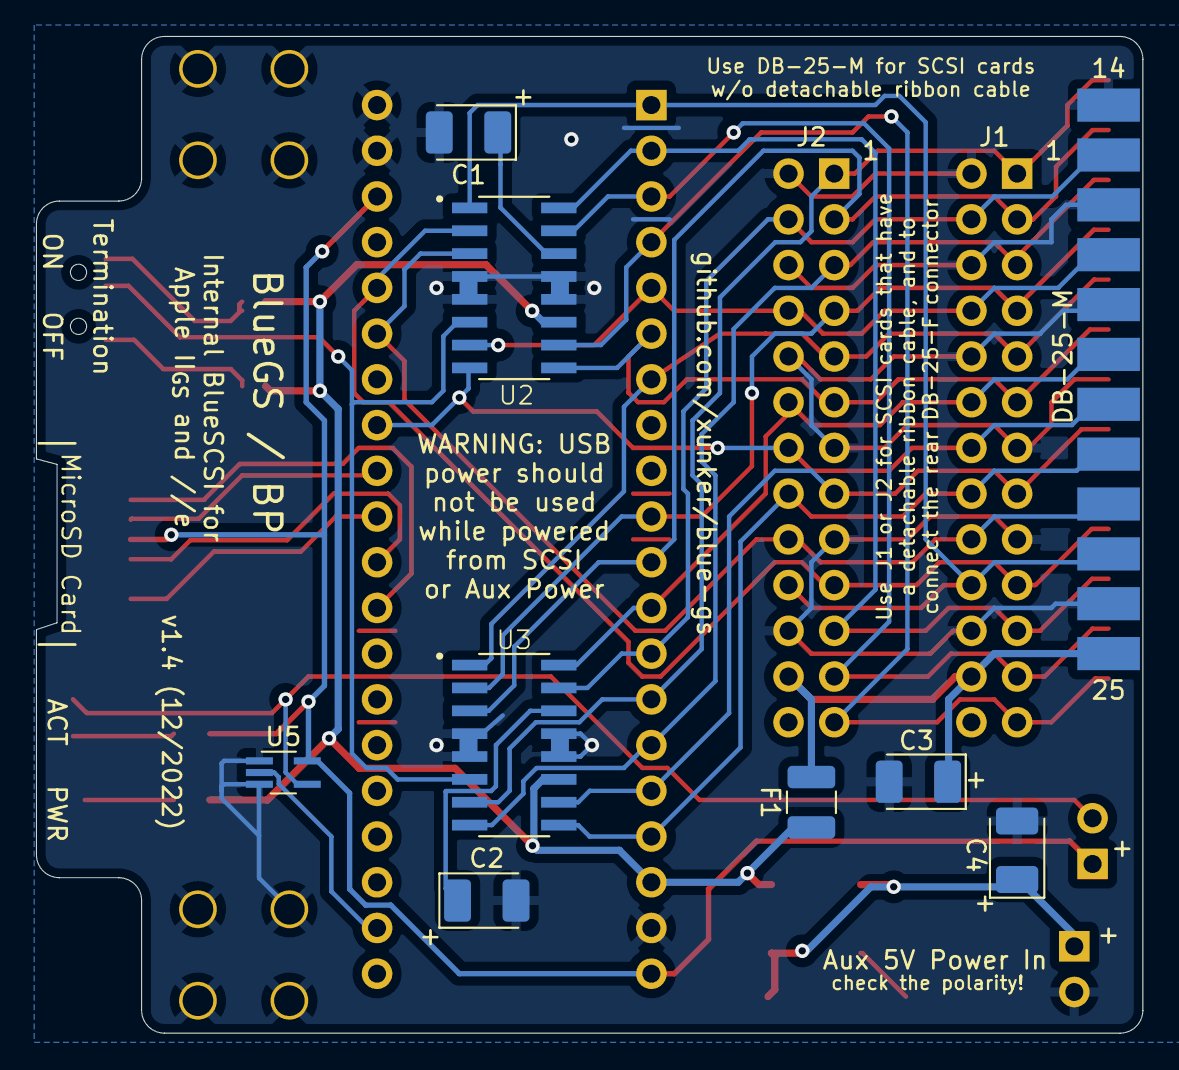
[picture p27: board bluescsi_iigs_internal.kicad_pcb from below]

Board: 2 copper layers, 61.5 x 55.4 mm, 27 parts (8 on the bottom side), 37 nets.

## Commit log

2021-04-02 Initial commit after v1.0 to fab
    [bluescsi_iigs_internal.kicad_pcb, bluescsi_iigs_internal.sch]
2021-04-12 V1.1 from v1.0 Fix IDC26 pin header to be correct! Change capacitor footprint to handsolder variant. Move mounting holes toward centre by about 2.54 and back by 2.54
    [bluescsi_iigs_internal.kicad_pcb, bluescsi_iigs_internal.sch]
2021-04-12 Increase trace size for +3.3v and +5v
    [bluescsi_iigs_internal.kicad_pcb]
2021-04-23 Fix db25 connector wiring
    [bluescsi_iigs_internal.kicad_pcb]
2021-04-23 move "shoulders" back more
    [bluescsi_iigs_internal.kicad_pcb]
2021-04-23 fix spacing
    [bluescsi_iigs_internal.kicad_pcb]
2021-04-23 Move mounting hole toward centre a bunch
    [bluescsi_iigs_internal.kicad_pcb]
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2021-04-25 change radius of inside shoulder to match outside
    [bluescsi_iigs_internal.kicad_pcb]
2021-04-25 Change switch to smd
    [bluescsi_iigs_internal.kicad_pcb, bluescsi_iigs_internal.sch]
2021-04-25 pull back the shoulders even more
    [bluescsi_iigs_internal.kicad_pcb]
2021-04-25 nudge leds, add groind vias
    [bluescsi_iigs_internal.kicad_pcb]
2021-04-25 nudge the switch out a little, since ground can still pass underneath it
    [bluescsi_iigs_internal.kicad_pcb]
2021-04-26 Add auxilliary 12v input
    [bluescsi_iigs_internal.kicad_pcb, bluescsi_iigs_internal.sch]
2021-04-26 Change footprint of diodes
    [bluescsi_iigs_internal.kicad_pcb, bluescsi_iigs_internal.sch]
2021-04-28 Change microsd slot to Molex 105162-0001. Add version number to back silkscreen
    [bluescsi_iigs_internal.sch]
2021-04-28 Remove UCC5606 from rear silk since will make this compatible with other ICs in future
    [bluescsi_iigs_internal.kicad_pcb]
2021-04-28 move rear termination text away from switch holes
    [bluescsi_iigs_internal.kicad_pcb]
2021-04-28 Add JPs to set the DISCNT signal level for compatibility with UC560x, UCC560x and UCC5612 terminator ICs
    [bluescsi_iigs_internal.kicad_pcb, bluescsi_iigs_internal.sch]
2021-04-30 Move kicad files to own directory
    [bluescsi_iigs_internal.kicad_pcb, bluescsi_iigs_internal.sch]
2021-04-30 remove the moved files
    [bluescsi_iigs_internal.kicad_pcb, bluescsi_iigs_internal.sch]
2021-05-01 Updated schematic to group items and make them more readable
    [bluescsi_iigs_internal.kicad_pcb, bluescsi_iigs_internal.sch]
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2021-05-01 Update silkscreens: * Power Warning * Nameing * URL
    [bluescsi_iigs_internal.kicad_pcb]
2021-05-01 Move via so both ground planes connect
    [bluescsi_iigs_internal.kicad_pcb]
2021-05-04 Name change to "Blue-GS"
    [bluescsi_iigs_internal.kicad_pcb]
2021-05-04 Update notes about which JP setting to use with UCC5612
    [bluescsi_iigs_internal.sch]
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2021-05-10 Increate termpwr track size
    [bluescsi_iigs_internal.kicad_pcb]
2021-05-10 Add another grounding track
    [bluescsi_iigs_internal.kicad_pcb]
2021-05-10 Add footprint for keystone 7774
    [bluescsi_iigs_internal.kicad_pcb]
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2021-05-13 Add p-mosfet driver for activity LED
    [bluescsi_iigs_internal.kicad_pcb, bluescsi_iigs_internal.sch]
2021-05-13 Added connector for external activity LED
    [bluescsi_iigs_internal.kicad_pcb, bluescsi_iigs_internal.sch]
2021-05-14 Replace mounting holes with Keystone 7774 brackets
    [bluescsi_iigs_internal.kicad_pcb, bluescsi_iigs_internal.sch]
2021-05-17 Adjust screw hole in slightly to account for screw width add silkscreen on rear for card slot
    [bluescsi_iigs_internal.kicad_pcb]
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2021-06-03 replace lef mostfest with logic inverter
    [bluescsi_iigs_internal.kicad_pcb, bluescsi_iigs_internal.sch]
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2021-06-10 Correct LED wiring for active-low with buffer IC
    [bluescsi_iigs_internal.kicad_pcb, bluescsi_iigs_internal.sch]
2021-06-10 Move the CD card slot back by about 3mm to protect the card more
    [bluescsi_iigs_internal.kicad_pcb]
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2021-06-15 Fix assembly ToC
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2021-06-17 Added schematic for v1.3 (non-final), removed rendered board pictures not that we have REAL pictureds
    [bluescsi_iigs_internal.sch]
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2021-06-21 Add edge-mount db-25-m for scsi cards with fixed cables
    [bluescsi_iigs_internal.kicad_pcb, bluescsi_iigs_internal.sch]
2021-06-21 Move db-25-m further up to help cable routing
    [bluescsi_iigs_internal.kicad_pcb]
2021-06-21 Move microsd silkscreen to match new placment, add marker on front for same
    [bluescsi_iigs_internal.kicad_pcb]
2021-06-21 move the regulator around so the screw hole doesn't overlap the blue pill footprint
    [bluescsi_iigs_internal.kicad_pcb]
2021-06-21 Change silkscreens and legends, reroute 3.3v line for better grounding
    [bluescsi_iigs_internal.kicad_pcb]
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2022-11-20 I should have done a changelog a long time ago
    [bluescsi_iigs_internal.kicad_pcb]
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2022-11-20 Change 7805 to UCC3916; nudge some traces to get better gnds
    [bluescsi_iigs_internal.kicad_pcb, bluescsi_iigs_internal.kicad_sch]
2022-12-02 Move power and led headers to better positon; Add indentation around microsd slot
    [bluescsi_iigs_internal.kicad_pcb]
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2022-12-02 Added compatibility for 74LVC1G125SE in place of NL17SZ07DFT2G
    [bluescsi_iigs_internal.kicad_pcb, bluescsi_iigs_internal.kicad_sch]
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2022-12-05 Make name more consistent, move sinkscreens around to make things look better
    [bluescsi_iigs_internal.kicad_pcb]
2022-12-05 Move power controller to front for better wire clearance in tight cases
    [bluescsi_iigs_internal.kicad_pcb]
2022-12-05 Move Termpower decoupling cap closer to the connector (as per specs)
    [bluescsi_iigs_internal.kicad_pcb]
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2022-12-05 Move some capacitors around, add more silkscreen notes
    [bluescsi_iigs_internal.kicad_pcb]
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2022-12-05 Push C4 a little higher to get it out of the way pf wires
    [bluescsi_iigs_internal.kicad_pcb]
2022-12-05 Give that via more space, we have it!
    [bluescsi_iigs_internal.kicad_pcb]
2022-12-05 move 3v3 via slightly so its inline with others
    [bluescsi_iigs_internal.kicad_pcb]
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2022-12-19 Fix overlapping text; change CC back to silkscreen
    [bluescsi_iigs_internal.kicad_pcb]
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2023-01-26 Change board branding to "BlueGS / BP" to distinguish it from rp2040-based design. Move cd card slot back slightly.
    [bluescsi_iigs_internal.kicad_pcb, bluescsi_iigs_internal.kicad_sch]
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
